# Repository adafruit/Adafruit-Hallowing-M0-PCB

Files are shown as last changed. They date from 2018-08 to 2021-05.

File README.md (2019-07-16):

## Adafruit HalloWing M0 Express PCB

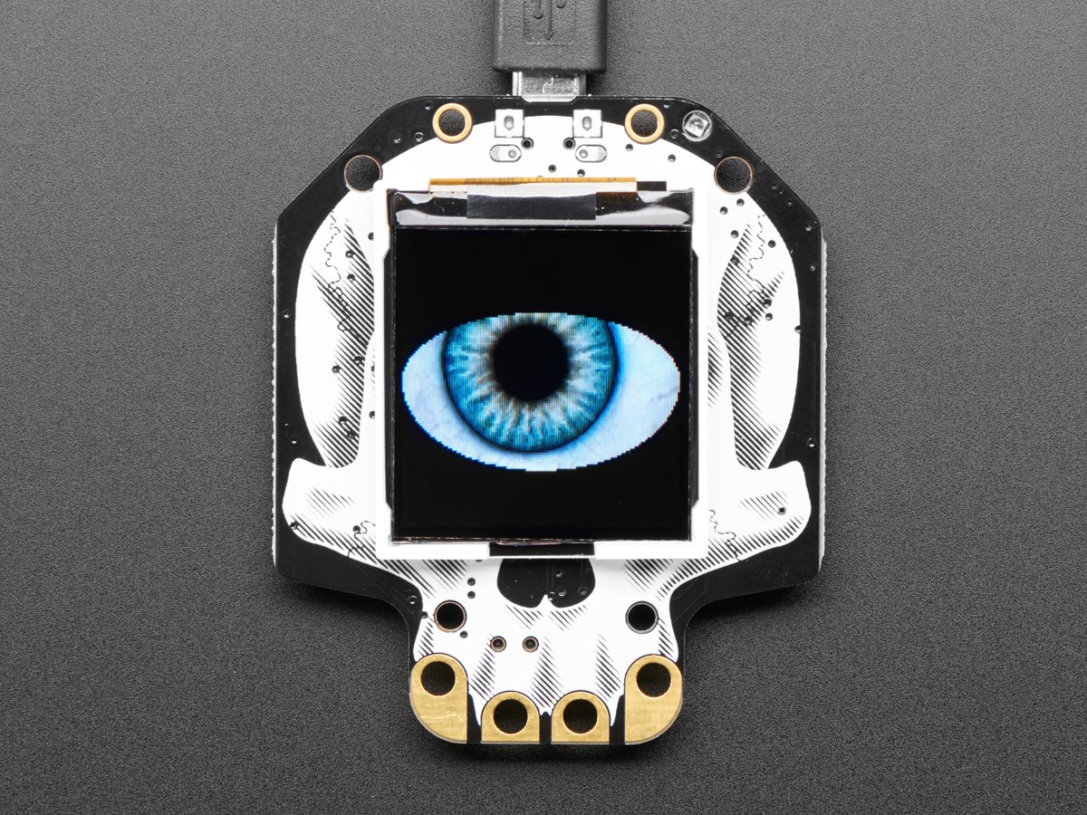
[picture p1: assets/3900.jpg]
<a href="http://www.adafruit.com/products/3900"><br/>
Click here to purchase one from the Adafruit shop</a>

PCB files for the Adafruit HalloWing M0 Express. Format is EagleCAD schematic and board layout
* https://www.adafruit.com/product/3900

### Description
[This is Hallowing..this is Hallowing... Hallowing! Hallowing!](https://www.youtube.com/watch?v=kGiYxCUAhks&t=39s)
Are you the kind of person who doesn't like taking down the skeletons and spiders until after January? Well, we've got the development board for you. This is electronics at its most spooky! The **Adafruit HalloWing** is a skull-shaped ATSAMD21 board with a ton of extras built in to make for an adorable wearable, badge, development kit, or the engine for your next cosplay or prop.

On the front is a cute **1.44" sized 128x128** full color TFT. Our default example code has our spooky eye demo running but you can use it for anything you like to display in glorious color.

There's also 4 fang-teeth below the display, these are analog/capacitive touch inputs with big alligator-clip holes.

On the reverse is a smorgasbord of electronic goodies:

 * **ATSAMD21G18** @ 48MHz with 3.3V logic/power - 256KB of FLASH + 32KB of RAM
 * **8 MB of SPI Flash** for storing images, sounds, animations, whatever!
 * **3-axis accelerometer** (motion sensor)
 * **Light sensor**, reverse-mount so that it points out the front
 * **Mono Class-D speaker driver** for 4-8 ohm speakers, up to 2 Watts, with mini volume pot
 * LiPoly battery port with built in recharging capability
 * USB port for battery charging, programming and debugging
 * Two female header strips with Feather-compatible pinout so you can plug any FeatherWings in
 * JST ports for Neopixels, sensor input, and I2C (you can fit I2C Grove connectors in here)
 * 3.3V regulator with 500mA peak current output
 * Reset button
 * On-Off switch

**OK so technically it's more like a really tricked-out Feather M0 Express than a Wing but we simply could not resist the Hallowing pun.**

Right now you can use the Hallowing similarly Feather M0 Express, it's got the same chip although the pins have been rearranged. We've got both Arduino and CircuitPython build support for it so you can pick your favorite development language! The extra 8 MB of SPI Flash is great for sound effects projects where you want to play up to 3 minutes of WAV files.

On each side of the Hallowing are JST-PH plugs for connecting external devices. The 3-pin JSTs connect to analog pins on the SAMD21, so you can use them for analog inputs. We label one for Neopixel and one for Sensors since we think most people will have one of each. The 4-pin JST connector connects to the I2C port and you can fit Grove connectors in it for additional hardware support.

**Does not come with a Lipoly battery!** [We recommend our 350mAh](https://www.adafruit.com/product/2750) or [500mAh batteries](https://www.adafruit.com/product/1578) but any 3.7/4.2V Adafruit Lipoly will do the trick.

Comes fully assembled and ready to be your spooky friend. We install the UF2 bootloader on it so updating code and converting it to CircuitPython is easy. [Check out the Adafruit Learn guide for software, libraries, example code, schematics, datasheets and more!](https://learn.adafruit.com/adafruit-hallowing)

### License

Adafruit invests time and resources providing this open source design, please support Adafruit and open-source hardware by purchasing products from [Adafruit](https://www.adafruit.com)!

Designed by Limor Fried/Ladyada for Adafruit Industries.

Creative Commons Attribution/Share-Alike, all text above must be included in any redistribution. See license.txt for additional details.

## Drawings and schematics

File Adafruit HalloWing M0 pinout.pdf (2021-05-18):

# Adafruit HalloWing M0 Express

## https://www.adafruit.com/product/3900

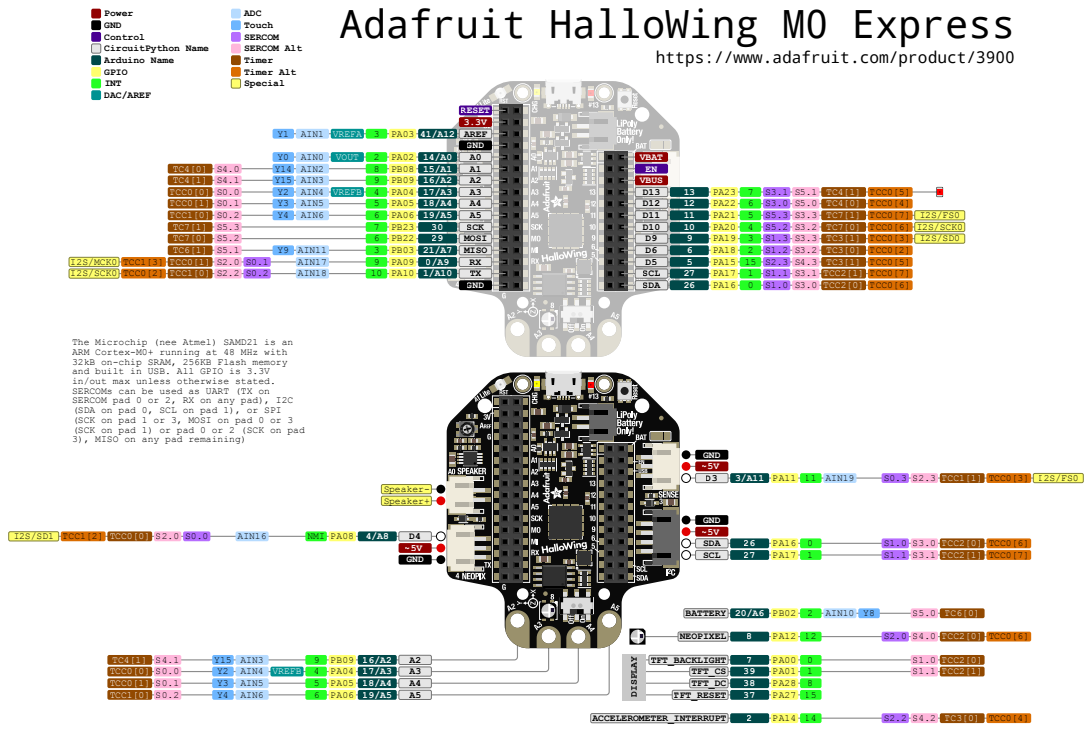
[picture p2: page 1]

The Microchip (nee Atmel) SAMD21 is an
ARM Cortex-M0+ running at 48 MHz with
32kB on-chip SRAM, 256KB Flash memory
and built in USB. All GPIO is 3.3V
in/out max unless otherwise stated.
SERCOMs can be used as UART (TX on
SERCOM pad 0 or 2, RX on any pad), I2C
(SDA on pad 0, SCL on pad 1), or SPI
(SCK on pad 1 or 3, MOSI on pad 0 or 3
(SCK on pad 1) or pad 0 or 2 (SCK on pad
3), MISO on any pad remaining)

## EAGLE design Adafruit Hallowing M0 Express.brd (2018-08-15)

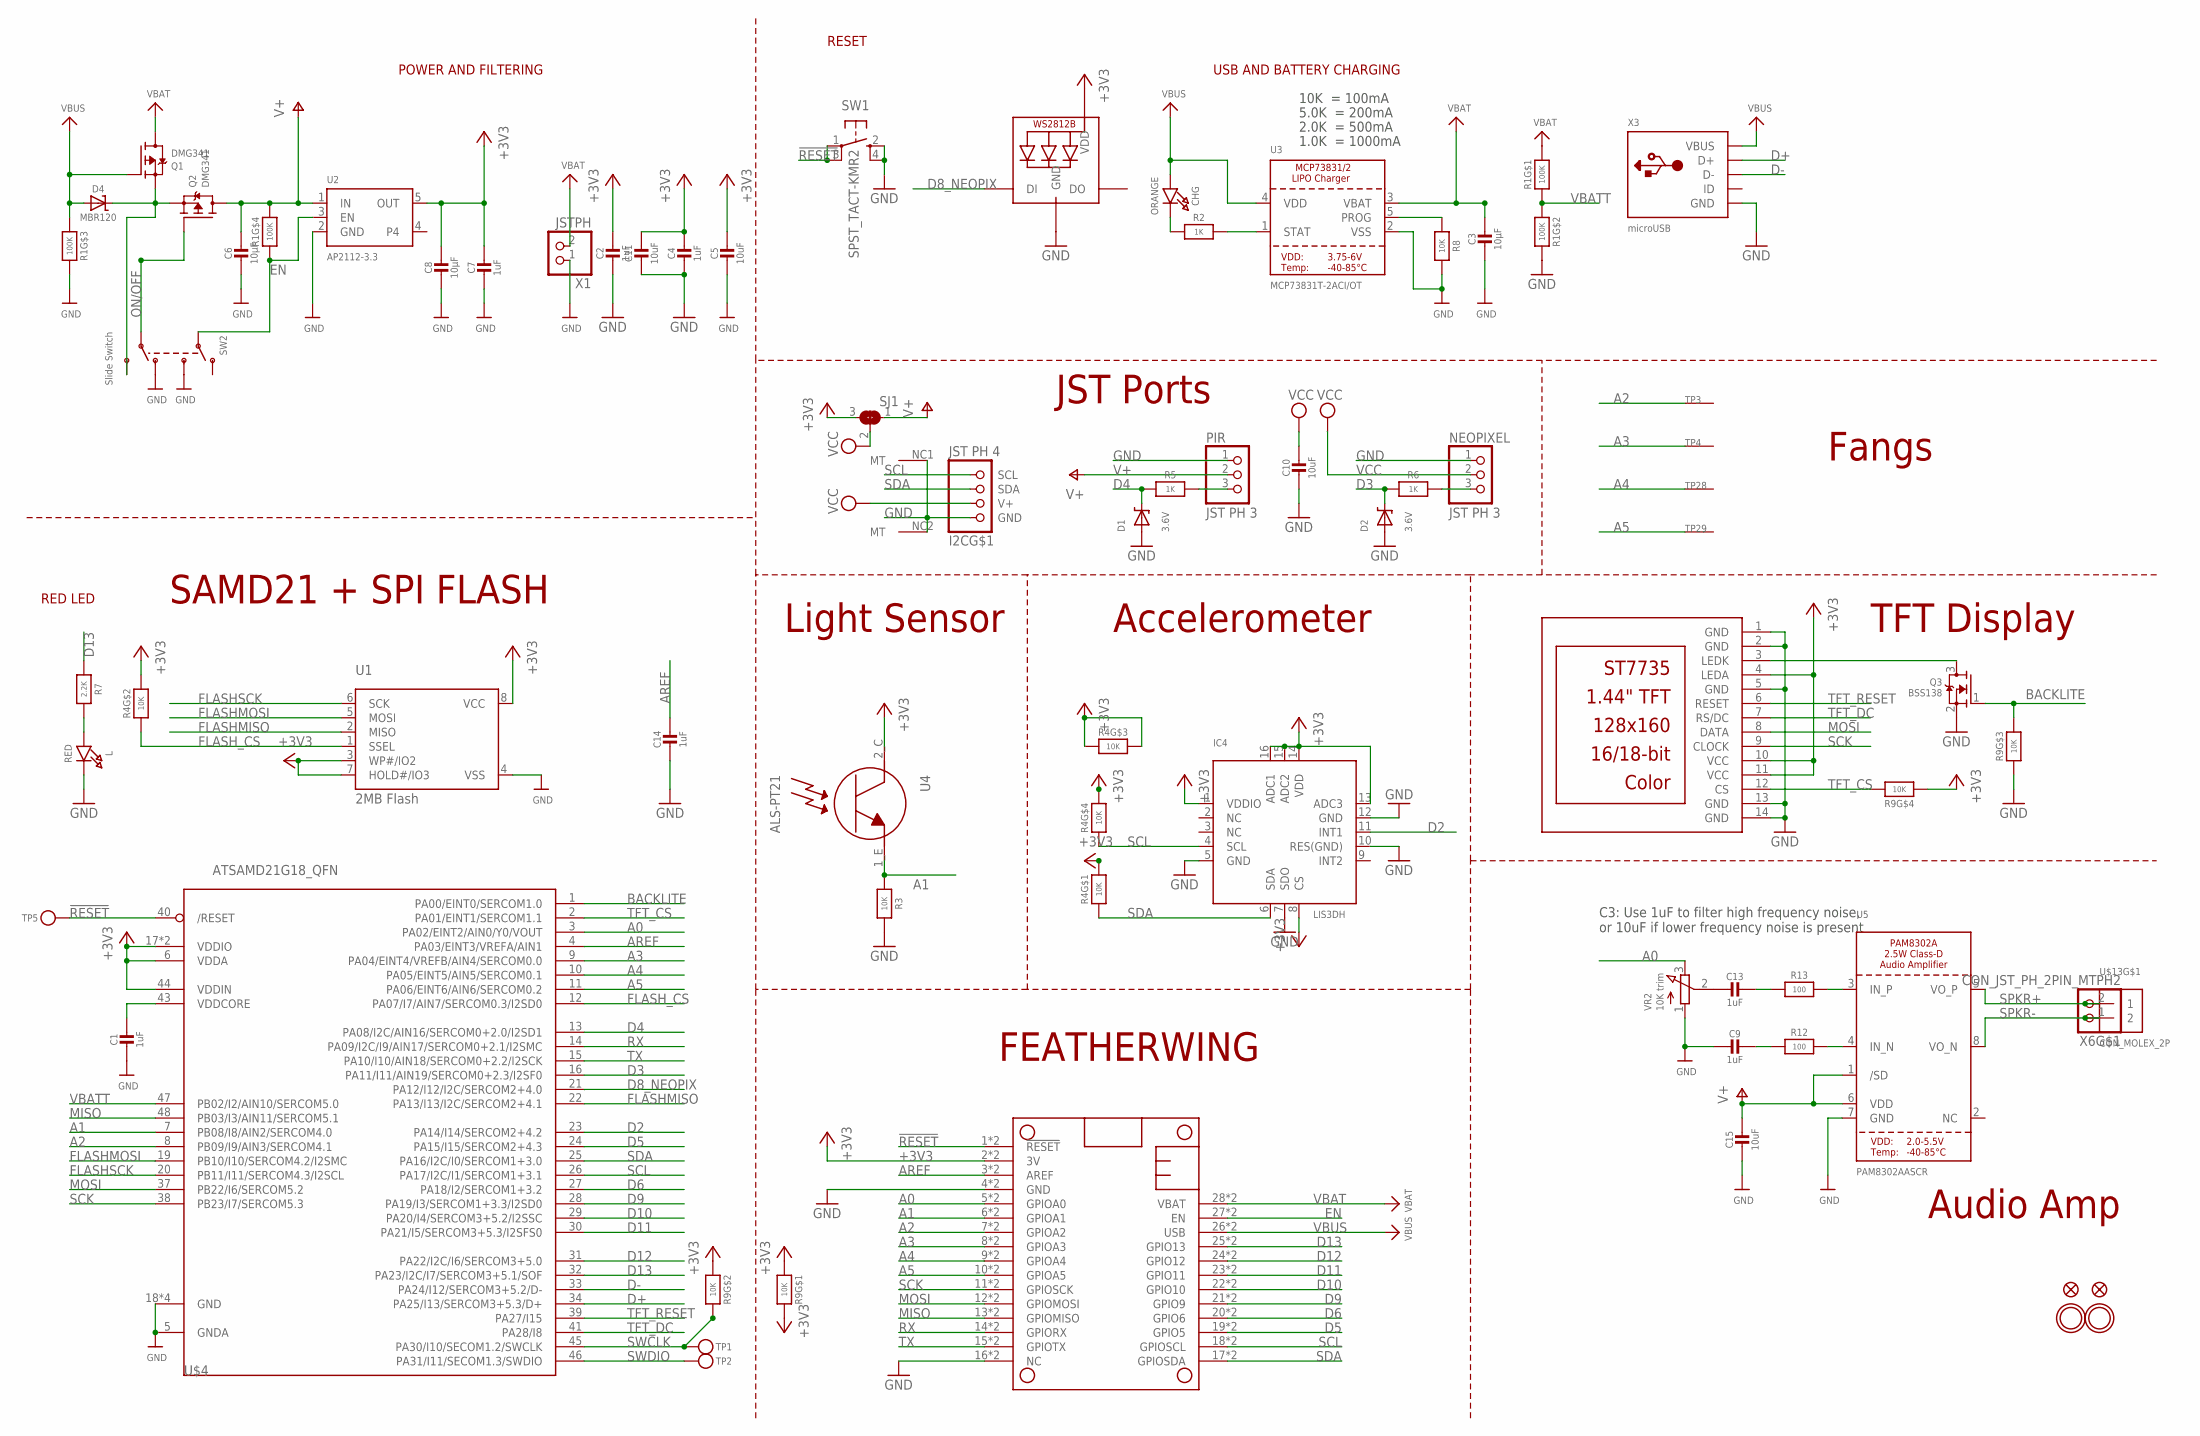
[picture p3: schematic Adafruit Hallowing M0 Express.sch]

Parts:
C1, C2, C4, C7, C9, C13, C14: 1uF; 0603-NO
C3, C6: 10µF; 0805-NO
C5, C10, C15: 10uF; 0805-NO
C8: 10µF; 0805_10MGAP
C11: 10uF; 0805_10MGAP
CHG: ORANGE; CHIPLED_0805_NOOUTLINE
D1, D2: 3.6V; SOD-323
D4: MBR120; SOD-123
I2C: JST PH 4; JSTPH4
IC4: LIS3DH; LGA16_3X3MM
L: RED; CHIPLED_0805_NOOUTLINE
LED1: WS2812B3535; LED3535
MS1: FEATHERWING_SMTDUALNOHOLES; FEATHERWING_SMT_NOHOLES
NEOPIXEL: JST PH 3; JSTPH3
PIR: JST PH 3; JSTPH3
Q1, Q2: DMG341; SOT23-R
Q3: BSS138; SOT23-WIDE
R1: 100K; RESPACK_4X0603
R2, R5, R6: 1K; 0603-NO
R3, R8: 10K; 0603-NO
R4, R9: 10K; RESPACK_4X0603
R7: 2.2K; 0603-NO
R12, R13: 100; 0603-NO
SJ1: SOLDERJUMPER_2WAY; SOLDERJUMPER_2WAY_OPEN_NOPASTE
SW1: SPST_TACT-KMR2; KMR2
SW2: Slide Switch; EG1390
TFT: DISP_LCD_ST7735_1.44IN; TFT_1.44IN_128_128
TP1, TP2, TP5: TESTPOINTROUND1.5MM; TESTPOINT_ROUND_1.5MM
TP3, TP29: SEWTAP_ALLILONG; PCB_ALLI_LONG
TP4, TP28: SEWTAPPCB_ALLIGATOR; PCB_ALLI
U1: 2MB Flash; SOIC8_208MIL
U2: AP2112-3.3; SOT23-5
U3: MCP73831T-2ACI/OT; SOT23-5
U4: ALS-PT21; ALS-PT26-21C
U5: PAM8302AASCR; MSOP8_0.65MM
U$4: ATSAMD21G18_QFN; TQFN48_7MM
U$13: CON_MOLEX_2P; 53398-0271
U$31, U$32: MOUNTINGHOLE2.5; MOUNTINGHOLE_2.5_PLATED
U$34, U$35: FIDUCIAL_1MM
VR2: 10K trim; TRIMPOT_BOURNS_3303W
X1: JSTPH; JSTPH2
X3: microUSB; 4UCONN_20329_V2
X6: CON_JST_PH_2PIN_MTPH2; JSTPH2

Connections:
!RESET: MS1.1 (!RESET), MS1.1' (!RESET), SW1.1, SW1.3 (P1), TP5.P$1, U$4.40 (/RESET)
+3V3: C2.1, C4.1, C5.1, C7.1, C8.1, C11.1, IC4.1 (VDDIO), IC4.8 (CS), IC4.13 (ADC3), IC4.14 (VDD), IC4.15 (ADC2), IC4.16 (ADC1), LED1.2 (VDD), MS1.2 (3V), MS1.2' (3V), R4.3 (1), R4.5 (2), R4.6 (2), R4.7 (2), R4.8 (2), R9.1, R9.2 (1), R9.4 (1), R9.8 (2), SJ1.3, TFT.4 (LEDA), TFT.10 (VCC), TFT.11 (VCC), U1.3 (WP#/IO2), U1.7 (HOLD#/IO3), U1.8 (VCC), U2.5 (OUT), U4.2_C (C), U$4.6 (VDDA), U$4.17 (VDDIO), U$4.36 (VDDIO), U$4.44 (VDDIN)
A0: MS1.5 (GPIOA0), MS1.5' (GPIOA0), U$4.3 (PA02/EINT2/AIN0/Y0/VOUT), VR2.3 (E)
A1: MS1.6 (GPIOA1), MS1.6' (GPIOA1), R3.2, U4.1_E (E), U$4.7 (PB08/I8/AIN2/SERCOM4.0)
A2: MS1.7 (GPIOA2), MS1.7' (GPIOA2), TP3.P$1, U$4.8 (PB09/I9/AIN3/SERCOM4.1)
A3: MS1.8 (GPIOA3), MS1.8' (GPIOA3), TP4.P$1, U$4.9 (PA04/EINT4/VREFB/AIN4/SERCOM0.0)
A4: MS1.9 (GPIOA4), MS1.9' (GPIOA4), TP28.P$1, U$4.10 (PA05/EINT5/AIN5/SERCOM0.1)
A5: MS1.10 (GPIOA5), MS1.10' (GPIOA5), TP29.P$1, U$4.11 (PA06/EINT6/AIN6/SERCOM0.2)
AREF: C14.1, MS1.3 (AREF), MS1.3' (AREF), U$4.4 (PA03/EINT3/VREFA/AIN1)
BACKLITE: Q3.1 (G), R9.6 (2), U$4.1 (PA00/EINT0/SERCOM1.0)
CHG_LED: R2.2, U3.1 (STAT)
CHG_RATE: R8.1, U3.5 (PROG)
D2: IC4.11 (INT1), U$4.23 (PA14/I14/SERCOM2+4.2)
D3: D2.C, R6.2, U$4.16 (PA11/I11/AIN19/SERCOM0+2.3/I2SF0)
D4: D1.C, R5.2, U$4.13 (PA08/I2C/AIN16/SERCOM0+2.0/I2SD1)
D5: MS1.19 (GPIO5), MS1.19' (GPIO5), U$4.24 (PA15/I15/SERCOM2+4.3)
D6: MS1.20 (GPIO6), MS1.20' (GPIO6), U$4.27 (PA18/I2/SERCOM1+3.2)
D8_NEOPIX: LED1.1 (DI), U$4.21 (PA12/I12/I2C/SERCOM2+4.0)
D9: MS1.21 (GPIO9), MS1.21' (GPIO9), U$4.28 (PA19/I3/SERCOM1+3.3/I2SD0)
D10: MS1.22 (GPIO10), MS1.22' (GPIO10), U$4.29 (PA20/I4/SERCOM3+5.2/I2SSC)
D11: MS1.23 (GPIO11), MS1.23' (GPIO11), U$4.30 (PA21/I5/SERCOM3+5.3/I2SFS0)
D12: MS1.24 (GPIO12), MS1.24' (GPIO12), U$4.31 (PA22/I2C/I6/SERCOM3+5.0)
D13: MS1.25 (GPIO13), MS1.25' (GPIO13), R7.1, U$4.32 (PA23/I2C/I7/SERCOM3+5.1/SOF)
D+: U$4.34 (PA25/I13/SERCOM3+5.3/D+), X3.D+
D-: U$4.33 (PA24/I12/SERCOM3+5.2/D-), X3.D-
EN: MS1.27 (EN), MS1.27' (EN), R1.4 (1), SW2.P1, U2.3 (EN)
FLASHMISO: U1.2 (MISO), U$4.22 (PA13/I13/I2C/SERCOM2+4.1)
FLASHMOSI: U1.5 (MOSI), U$4.19 (PB10/I10/SERCOM4.2/I2SMC)
FLASHSCK: U1.6 (SCK), U$4.20 (PB11/I11/SERCOM4.3/I2SCL)
FLASH_CS: R4.2 (1), U1.1 (SSEL), U$4.12 (PA07/I7/AIN7/SERCOM0.3/I2SD0)
GND: C1.2, C2.2, C3.2, C4.2, C5.2, C6.2, C7.2, C8.2, C9.2, C10.2, C11.2, C14.2, C15.2, D1.A, D2.A, I2C.1 (GND), I2C.NC1 (MT), I2C.NC2 (MT), IC4.5 (GND), IC4.7 (SDO), IC4.10 (RES(GND)), IC4.12 (GND), L.C, LED1.4 (GND), MS1.4 (GND), MS1.4' (GND), MS1.16 (NC), MS1.16' (NC), NEOPIXEL.1, PIR.1, Q3.2 (S), R1.6 (2), R1.7 (2), R3.1, R8.2, R9.3 (1), SW1.2 (S), SW1.4 (S1), SW2.O2, SW2.S1, TFT.1 (GND), TFT.2 (GND), TFT.5 (GND), TFT.13 (GND), TFT.14 (GND), U1.4 (VSS), U2.2 (GND), U3.2 (VSS), U5.7 (GND), U$4.5 (GNDA), U$4.18 (GND), U$4.35 (GND), U$4.42 (GND), U$4.THERMAL (GND), VR2.1 (A), X1.1, X3.BASE@1 (GND), X3.BASE@2 (GND), X3.GND, X3.SPRT@1 (GND), X3.SPRT@2 (GND), X3.SPRT@3 (GND), X3.SPRT@4 (GND)
MISO: MS1.13 (GPIOMISO), MS1.13' (GPIOMISO), U$4.48 (PB03/I3/AIN11/SERCOM5.1)
MOSI: MS1.12 (GPIOMOSI), MS1.12' (GPIOMOSI), TFT.8 (DATA), U$4.37 (PB22/I6/SERCOM5.2)
unnamed: CHG.C, R2.1
unnamed: L.A, R7.2
unnamed: Q3.3 (D), TFT.3 (LEDK)
unnamed: D4.C, Q1.2 (S), Q2.2 (S), SW2.S2
unnamed: R12.2, U5.4 (IN_N)
unnamed: R13.2, U5.3 (IN_P)
unnamed: C9.1, R12.1
unnamed: C13.1, R13.1
unnamed: C13.2, VR2.2 (S)
NEOPIXELOUT: NEOPIXEL.3, R6.1
ON/OFF: Q2.1 (G), SW2.P2
RX: MS1.14 (GPIORX), MS1.14' (GPIORX), U$4.14 (PA09/I2C/I9/AIN17/SERCOM0+2.1/I2SMC)
SCK: MS1.11 (GPIOSCK), MS1.11' (GPIOSCK), TFT.9 (CLOCK), U$4.38 (PB23/I7/SERCOM5.3)
SCL: I2C.4 (SCL), IC4.4 (SCL), MS1.18 (GPIOSCL), MS1.18' (GPIOSCL), R4.4 (1), U$4.26 (PA17/I2C/I1/SERCOM1+3.1)
SDA: I2C.3 (SDA), IC4.6 (SDA), MS1.17 (GPIOSDA), MS1.17' (GPIOSDA), R4.1, U$4.25 (PA16/I2C/I0/SERCOM1+3.0)
SENSORIN: PIR.3, R5.1
SPKR+: U5.5 (VO_P), U$13.1, X6.2
SPKR-: U5.8 (VO_N), U$13.2, X6.1
SWCLK: R9.7 (2), TP1.P$1, U$4.45 (PA30/I10/SECOM1.2/SWCLK)
SWDIO: TP2.P$1, U$4.46 (PA31/I11/SECOM1.3/SWDIO)
TFT_CS: R9.5 (2), TFT.12 (CS), U$4.2 (PA01/EINT1/SERCOM1.1)
TFT_DC: TFT.7 (RS/DC), U$4.41 (PA28/I8)
TFT_RESET: TFT.6 (RESET), U$4.39 (PA27/I15)
TX: MS1.15 (GPIOTX), MS1.15' (GPIOTX), U$4.15 (PA10/I10/AIN18/SERCOM0+2.2/I2SCK)
V+: C6.1, C15.1, PIR.2, Q2.3 (D), R1.5 (2), SJ1.1, U2.1 (IN), U5.1 (/SD), U5.6 (VDD)
VBAT: C3.1, MS1.28 (VBAT), MS1.28' (VBAT), Q1.3 (D), R1.8 (2), U3.3 (VBAT), X1.2
VBATT: R1.1, R1.2 (1), U$4.47 (PB02/I2/AIN10/SERCOM5.0)
VBUS: CHG.A, D4.A, MS1.26 (USB), MS1.26' (USB), Q1.1 (G), R1.3 (1), U3.4 (VDD), X3.VBUS
VCC: C10.1, I2C.2 (V+), NEOPIXEL.2, SJ1.2
VDDCORE: C1.1, U$4.43 (VDDCORE)

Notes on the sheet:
POWER AND FILTERING
RESET
10K = 100mA
5.0K = 200mA
2.0K = 500mA
1.0K = 1000mA
USB AND BATTERY CHARGING
RED LED
C3: Use 1uF to filter high frequency noise, or 10uF if lower frequency noise is present
Accelerometer
Light Sensor
FEATHERWING
SAMD21 + SPI FLASH
Fangs
TFT Display
Audio Amp
JST Ports

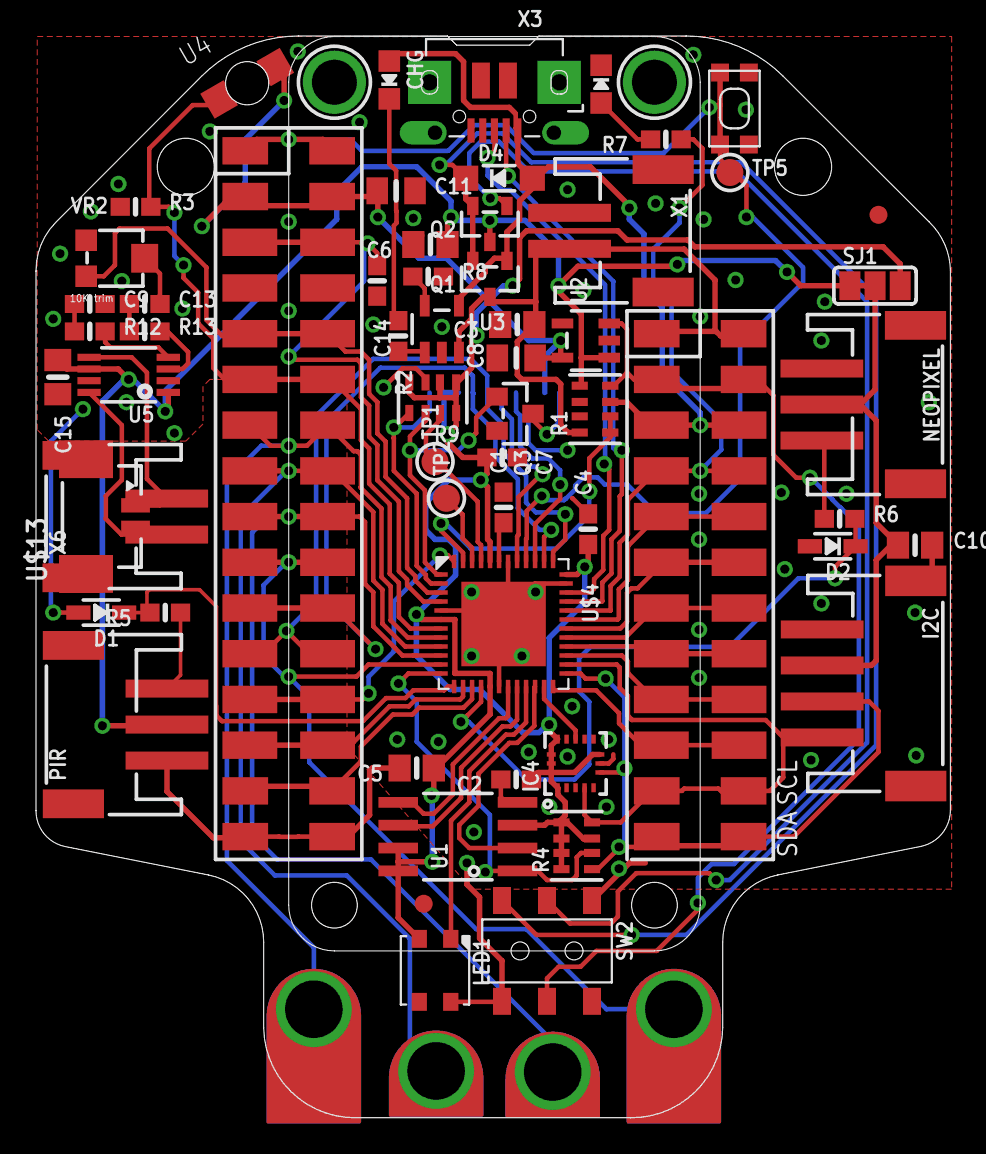
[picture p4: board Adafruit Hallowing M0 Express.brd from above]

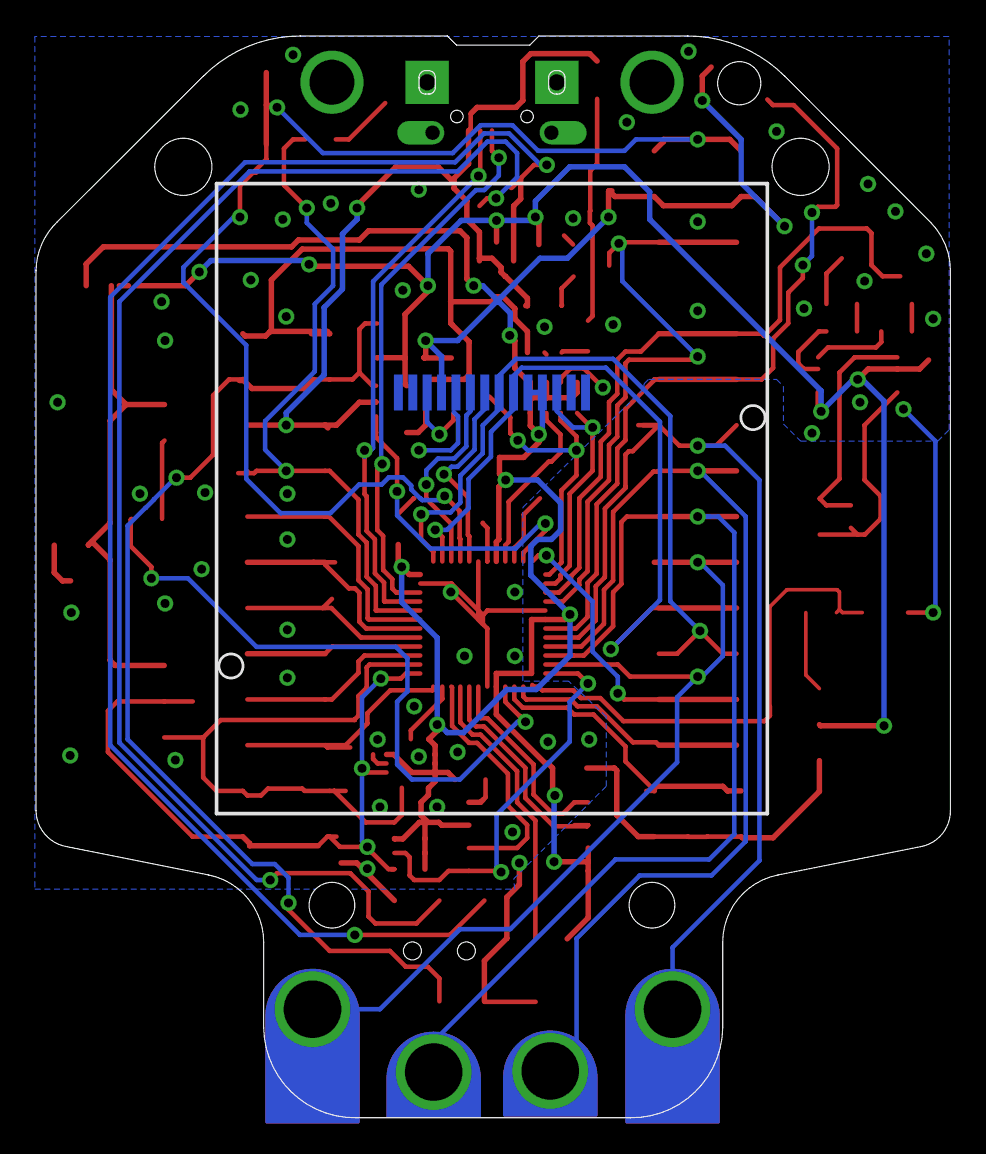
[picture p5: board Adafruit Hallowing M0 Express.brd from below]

Board: 2 copper layers, 50.8 x 60.1 mm, 67 parts (2 on the bottom side), 63 nets.

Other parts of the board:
U$8: HALLOWING_BACK
U$12: HALLOWING_FRONT

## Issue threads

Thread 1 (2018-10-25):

I am trying to upload the blink program to my Hallowing.  I am getting this error message:

Larkenware, 2018-10-25:
I updated all the libraries, updated the Arduino and adafruit SAMD board library.  Got the same error message.  Deleted everything and started over.  Unsure what to do next.  I accidentally posted this in the wrong forum earlier.  Sorry...new to github.

Arduino: 1.8.7 (Mac OS X), TD: 1.44, Board: "Adafruit Hallowing M0"

In file included from /Users/larkenware/Library/Arduino15/packages/arduino/tools/CMSIS-Atmel/1.2.0/CMSIS/Device/ATMEL/samd21/include/samd21.h:69:0,
                 from /Users/larkenware/Library/Arduino15/packages/arduino/tools/CMSIS-Atmel/1.2.0/CMSIS/Device/ATMEL/samd.h:105,
                 from /Users/larkenware/Library/Arduino15/packages/arduino/tools/CMSIS-Atmel/1.2.0/CMSIS/Device/ATMEL/sam.h:540,
                 from /Users/larkenware/Library/Arduino15/packages/adafruit/hardware/samd/1.2.3/cores/arduino/Arduino.h:48,
                 from sketch/Blink.ino.cpp:1:
/Users/larkenware/Library/Arduino15/packages/arduino/tools/CMSIS-Atmel/1.2.0/CMSIS/Device/ATMEL/samd21/include/samd21g18a.h:237:26: fatal error: core_cm0plus.h: No such file or directory
 #include <core_cm0plus.h>
                          ^
compilation terminated.
exit status 1
Error compiling for board Adafruit Hallowing M0.

This report would have more information with
"Show verbose output during compilation"
option enabled in File -> Preferences.

ladyada, 2018-10-25:
hiya this is a tech support question not a PCB github issue... please post on the adafruit forums! :)

Closed 2018-10-25.

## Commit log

2018-09-11 lens holder
2019-07-16 updated to use the new pcb repo cookiecutter

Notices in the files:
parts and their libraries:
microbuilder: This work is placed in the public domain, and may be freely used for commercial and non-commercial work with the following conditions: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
